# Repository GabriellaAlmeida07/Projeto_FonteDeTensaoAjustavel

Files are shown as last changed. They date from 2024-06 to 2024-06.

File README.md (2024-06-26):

# Projeto_FonteDeTensaoAjustável
## Descrição:
Projeto da disciplina SSC0180 - Eletrônica para Computação, ministrada pelo professor Eduardo do Valle Simoes, com o objetivo de projetar uma
fonte reficadora capaz de transformar corrente alternada de tensão, em corrente contínua, com valor de tensão ajustável entre 3 e 12 volts.

## Componentes:

| Componente |  Quantidade | Especificações | Valor Unitário |
|:---:|:---:|:---:|:---:|
| Diodo Retificador | 5 | 1N4007 LGE=1N4004 | R$ 0,20 |
| Capacitor | 1 | 680UFX25V | R$ 5,80 |
| LED | 2 | 5mm VM difuso | R$ 0,50 |
| Resistor | 5 | CR25 3K3 | R$ 0,07 |
| Resistor | 5 | CR25 1K | R$ 0,07 |
| Resistor | 5 | CR25 4K7 | R$ 0,07 |
| Resistor | 5 | CR25 120R | R$ 0,07 |
| Resistor | 5 | CR25 680R | R$ 0,07 |
| Diodo Zener | 2 | 13V 1W - 1N4743 | R$ 0,50 |
| Potenciômetro | 2 | 1W B10K B-16 | R$ 7,00 |
| Transistor | 1 | BC368 N-25V-1A-0  | R$ 0.44 |
| Jumper Macho | 10 | 20cm | R$ 0,70 |
| Fusível | 2 | 20 AG 0.1A | R$ 1,10 |
| Varistor | 1 | 150VAC 7D 241K | R$ 1,50 |
|**Total** | | | **R$ 35,69** |

## Sobre os componentes
#### Transformador:
A fonte de corrente alternada (tomada) fornece uma ddp de 127V, por isso é necessário o uso do transformador que é capaz de baixar a tensão de 110 volts para 12 volts.

#### Fusível:
O fusível é usado com o intuito de "proteger" o circuito de correntes elétricas excessivas, visto que se houver sobrecarga, ele irá interromper o circuito.

#### Ponte de diodos:
Formada por quatro diodos retificadores, é responsável por permitir que uma corrente alternada seja convertida em corrente contínua.

#### Varistor:
Também usado para maior segurança ao circuito, pois quando uma tensão excessiva é aplicada ao varistor, sua resistência diminui rapidamente, permitindo que ele conduza a corrente elétrica e desvie a energia extra para a terra ou para a fonte de alimentação.

#### Capacitor:
Responsável por controlar a ondulação da tensão no circuito, durante a alternância dos ciclos de corrente elétrica, o capacitor armazena energia (quando a tensão está alta) e libera quando a tensão cai.

#### Resistor:
O resistor limita o fluxo de corrente elétrica em um circuito, impedindo que a corrente ultrapasse o limite estabelecido por cada componente.

#### Diodo Zener:
Se comporta como um diodo normal, porém quando a tensão excede a tensão Zener, ele deixará "passar" somente a tensão limite, que no caso será 12V.

#### Transistor:
O transistor tem capacidade de controle da intensidade da corrente elétrica que passa por ele, sendo capaz de limitá-la, amplificá-la ou, até mesmo, atenuá-la.

#### Potenciômetro:
É um tipo de resistor que permite controlar a tensão entre 3 a 12V, no nosso caso.

## Fotos do circuito na protoboard
2db8313d-9aef-4dc3-9cda-20fbeb00f63c

5edc806d-a50e-4728-a3e1-ea7236ce99d1

## Circuito Falstad
[Circuito Falstad](https://tinyurl.com/2gfmwb9f)

Captura de tela de 2024-06-26 18-35-03

## Projeto do Esquemático EAGLE

Captura de tela 2024-06-18 152255

## Projeto PCB EAGLE
Captura de tela 2024-06-18 151144

## Cálculos
Queremos um Ripple pequeno (10%), e por isso é possível utilizar a fórmula simplificada C = i / (f * v) * ripple.

Seguindo o simulador Falstad, encontramos a tensão após a ponte de diodos de aproximadamente 18.18V e a corrente depois do capacitor de aproximadamente 120mA.

Sabemos que a fonte possui uma corrente alternada de 60Hz, daí obtemos f a partir de 2 * 60 = 120Hz, então basta aplicar a fórmula sobre os valores encontrados.

O resultado desta operação foi de 550uF, porém preferimos comprar um capacitor de 680uF (o segundo valor comercial mais próximo), por segurança.

## Vídeo do projeto

Captura de tela de 2024-06-26 18-40-31 (https://youtube.com/shorts/gmYSijptPVI?feature=share)

## Colaboradoes:
Gabriella Almeida - 15528121

Samuel Sandoval Bonachela - 13686282

Joao Victor De Bortoli Prado - 13672071

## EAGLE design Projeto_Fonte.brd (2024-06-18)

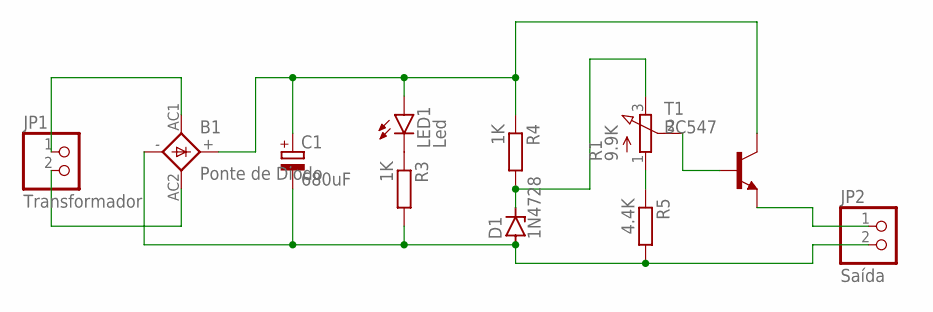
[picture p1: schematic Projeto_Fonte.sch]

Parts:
B1: Ponte de Diodo; 1KAB
C1: 680uF; E5-10,5
D1: 1N4728; DO41Z10
JP1: Transformador; 1X02
JP2: Saída; 1X02
LED1: Led; LED5MM
R1: 9.9K; 3RP/1610N
R3, R4: 1K; 0204/7
R5: 4.4K; 0204/7
T1: BC547; TO92

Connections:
unnamed: B1.AC1, JP1.1
unnamed: B1.AC2, JP1.2
unnamed: B1.+, C1.+, LED1.A, R4.1, T1.3 (C)
unnamed: B1.-, C1.-, D1.A, JP2.2, R3.2, R5.2
unnamed: LED1.K (C), R3.1
unnamed: D1.C, R1.3 (E), R4.2
unnamed: R1.1 (A), R5.1
unnamed: R1.2 (S), T1.2 (B)
unnamed: JP2.1, T1.1 (E)

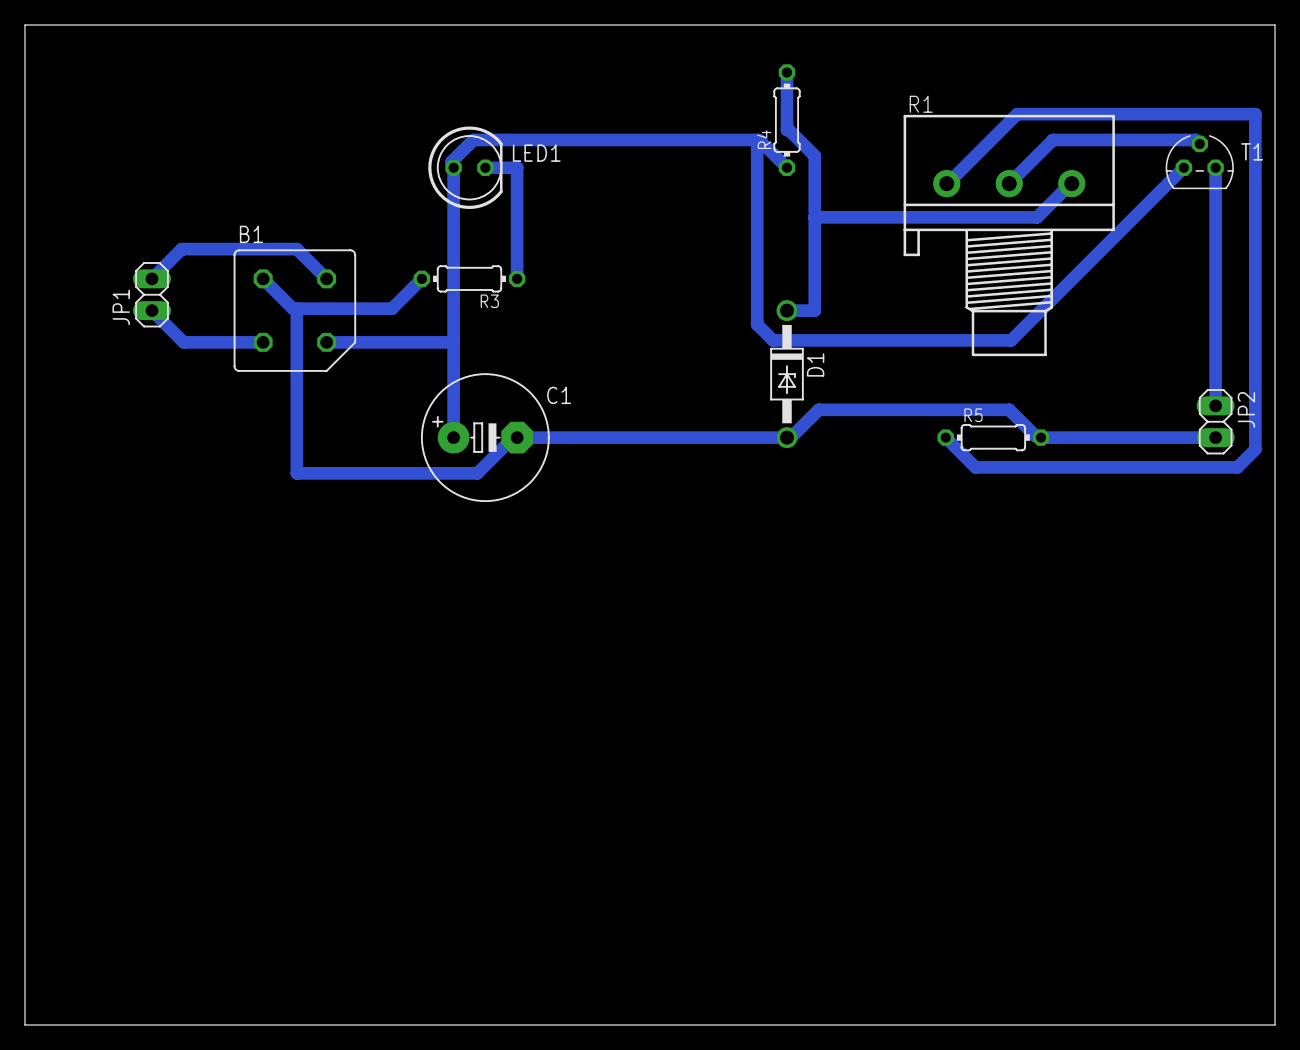
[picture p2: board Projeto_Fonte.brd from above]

Board: 2 copper layers, 100.0 x 80.0 mm, 11 parts (0 on the bottom side), 9 nets.
